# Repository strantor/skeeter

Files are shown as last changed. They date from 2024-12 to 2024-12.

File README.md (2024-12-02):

# skeeter
- Plastic welding spoolgun
- Over Engineered hot glue gun
- Under Engineered 3D printer (handheld)
- 3D pen on steroids

This tool is designed to make the welding together of 3D printed parts go quickly.
It operates from DeWalt 20V battery power or a 24V power supply; there are two handle variants you can print depending on how you want to power it.



BOM:
1. 1X pair of printed parts
2. 1x [DeWalt Battery holder](https://www.amazon.com/gp/product/B0C282C27R/ref=ppx_yo_dt_b_search_asin_title?ie=UTF8&psc=1) (if you want battery powered)
3. 1x Orbiter 2 extruder
4. 1x 2510 fan 24V
5. 1x [Pololu DC motor](https://www.pololu.com/product/3491)
6. 1x [Peopoly Lancer Long hotend](https://peopoly.net/products/magneto-x-lancer-melt-zone?variant=49972216135962)
7. 1x [FA2-16/WEK drill trigger motor controller](https://www.amazon.com/gp/product/B08PKZ464X/ref=ppx_yo_dt_b_search_asin_title?ie=UTF8&psc=1)
8. 1x [MKS THR42 3d printer toolhead board](https://makerbase3d.com/product/mks-thr36-thr42-board/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)
9. 4x 8-32 x0.5" countersunk screws
10. 4X M3x5mm standoffs
11. assortment of misc M3 screws
12. 18 awg wire 

Instructions:
1. print the parts. handle1.stl is for non-battery power and handle2 is for DeWalt battery power; you don't need both, just one or the other.
2. remove the stepper motor from the orbiter extruder
3. fabricate/machine a motor adapter plate and shaft adapter to mount the Pololu motor in place of the orbiter stepper
4. tap holes in the 3D printed parts. The 4 holes that hold the top part to the bottom are 8-32 and everything else is M3
5. assemble everything. T
6. Connect to the gun to PC via USB and flash the skeeter.uf2 file to the THR42 board via [MKS's firmware update instructions](https://github.com/makerbase-mks/MKS-THR36-THR42-UTC?tab=readme-ov-file#thr3642-firmware-update) . Ignore all the stuff about klipper config; this is not klipper firmware, it is a totally separate firmware that I wrote, to control the THR42 board as it's own standalone thing.
7. With the gun connected, to PC, connect to it using a terminal app like Putty or Arduino serial monitor. Send it a temperature (C) setpoint command like "S220" (without quotes) to set 220C.
8. It shouldn't need any PID tune adjustments if using Peopoly Lancer Long, but if using something else you can change the PID parameters by typing (for example): [Pxxx.xxx - Set PID Proportional constant. Ex: P2.25], [Ixxx.xxx - Set PID Integral constant. Ex: I0.25], [Dxxx.xxx - Set PID Derivative constant. Ex: D1.525]
9. Go shoot plastic!

The skeeter.uf2 firmware file is generated by Arduino IDE using the skeeter.ino file which you are welcome to modify however you want.

**NOTE: there is no low voltage cutout circuit on this tool so if you use the battery powered version, it is 100% capable of discharging your battery down to damaging levels!**

Help wanted! it's kinda silly to have to remove the stepper from the orbiter extruder and replace it with a DC motor (and go to the hassle of fabricating the adapters), when there is a THR42 board already on the tool that has a TMC2209 stepper driver on it. If someone wants to help out, figure out how to take the high voltage PWM signal from the trigger control and drop it down to a low voltage input (voltage divider? optocoupler?) to the THR42 board. Then use the THR42 board to control the stepper in a quasi-analog fashion (as you would expect a trigger-controlled tool to operate).

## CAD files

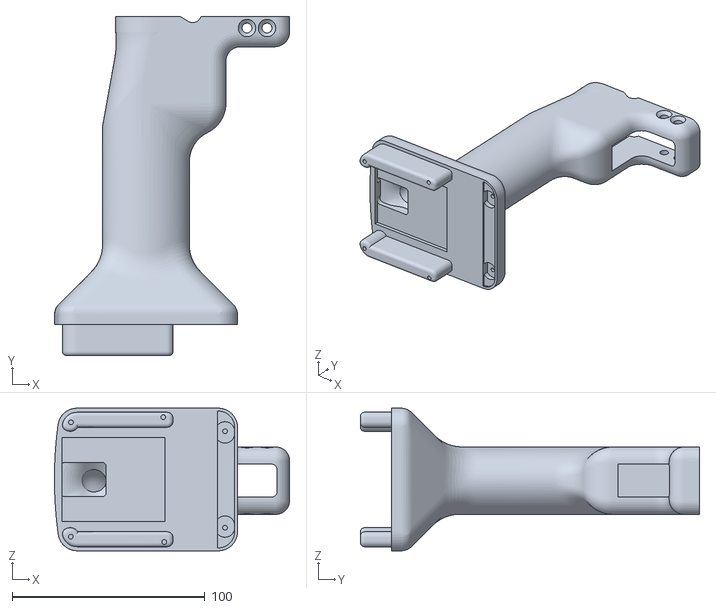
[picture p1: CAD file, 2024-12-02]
handle2.stl
122.0 x 175.8 x 74.0

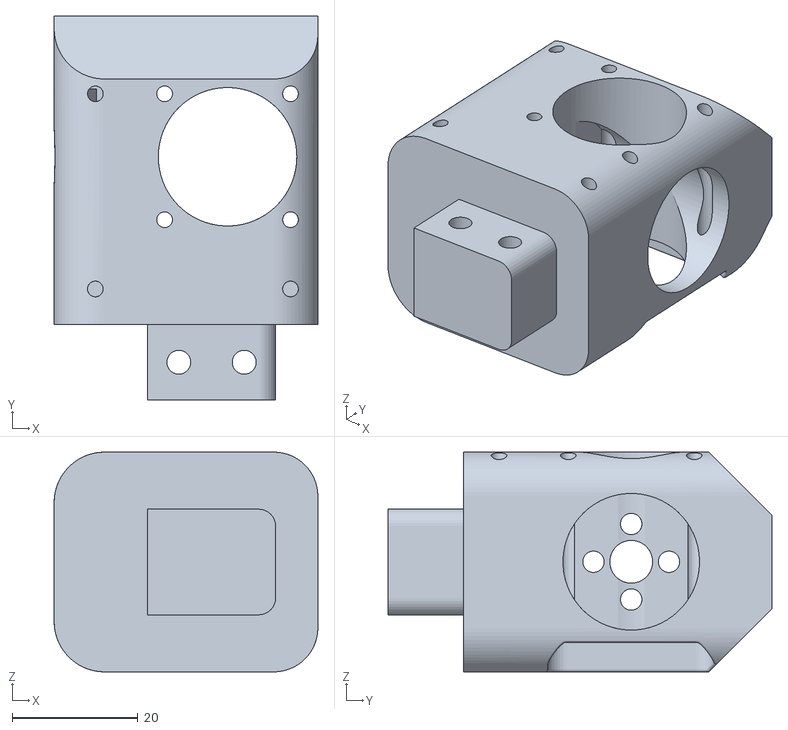
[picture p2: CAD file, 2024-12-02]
upper.stl
41.9 x 61.0 x 34.9

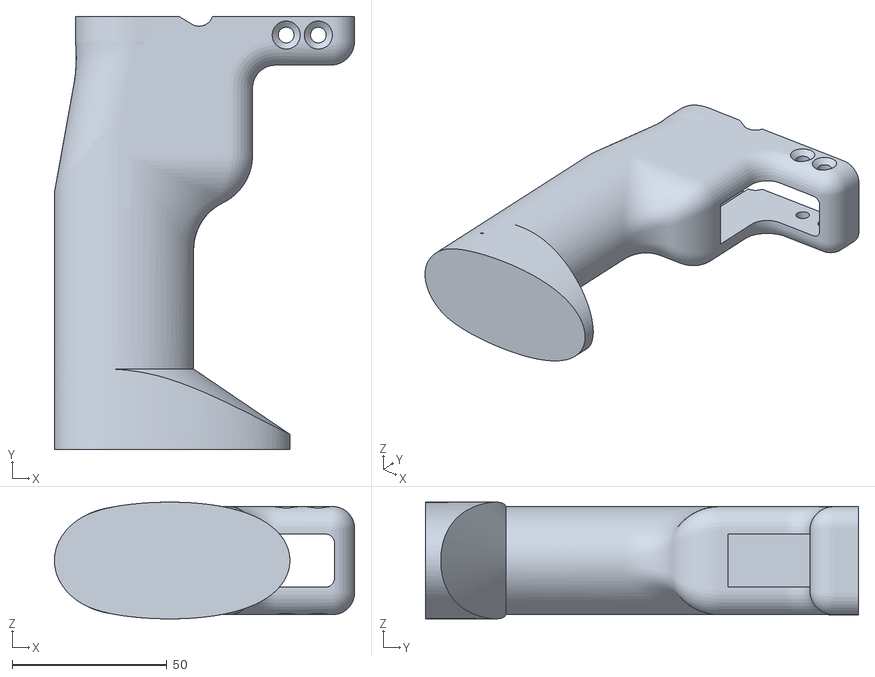
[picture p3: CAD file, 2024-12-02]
handle1.stl
97.0 x 139.9 x 37.7

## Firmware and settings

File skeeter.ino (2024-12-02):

// 12/2/24 Chuck Staton

// this is written for RP2040 (MKS THR42 board) in Arduino IDE. You must use https://github.com/earlephilhower/arduino-pico/
// setup instructions for installing the github package: https://www.tomshardware.com/how-to/program-raspberry-pi-pico-with-arduino-ide

// I'm shit at programming anything but Python. This is a collection of other people's code that I found online, copied, pasted, and modified to fit my needs. 
// I don't remember where some of it came from, but here is a list of citations that should cover most of the important stuff:
// - Arduino PID temperature implementation (was kinda wack, needed help, but "worked"): https://electronoobs.com/eng_arduino_tut24_code2.php#google_vignette
// - Serial input basics. I think it's an excellent tutorial and serial in Arduino just sucks. I could be wrong; the tutorial could suck. https://forum.arduino.cc/t/serial-input-basics-updated/382007
// - Abducar's thermistor lookup table code. https://forum.arduino.cc/t/how-to-use-ntc-100k-thermistor-to-measure-high-temperature/472821/13
// - How to EEPROM https://docs.arduino.cc/learn/programming/eeprom-guide/

// The EEPROM stuff is Earle F. Philhower's simulation of EEPROM which is actually stored on Pico's flash, so try not to write too often to it.
// Commands which can be typed into the serial monitor:
// Sxxx - Set temperature (C). Ex: "S235" - sets setpoint to 235C
// Pxxx.xxx - Set PID Proportional constant. Ex: P2.25
// Ixxx.xxx - Set PID Integral constant. Ex: I0.25
// Dxxx.xxx - Set PID Derivative constant. Ex: D1.525
// PID and temperature setpoints survive power cycle, so just set it initially and it should work whenever powered on.

// TODO: 
// - Make a way to attach a potentiometer or something so you don't have to connect to PC to change the temp setpoint
// - Utilize the THR42's onboard TMC2209 to control a stepper in quasi-analog style in response to PWM input from finger trigger controller (emulate a DC motor). 

#include <EEPROM.h>
#define THERMISTOR_PIN A0
#define NUMTEMPS 20
// The following lookup table was found online and is not an exact match for the Peopoly thermistor but close enough. 
// I did try the converted lookup table from the peopoly 
short temptable[NUMTEMPS][2] = {
   {1, 821},
   {54, 252},
   {107, 207},
   {160, 182},
   {213, 165},
   {266, 152},
   {319, 141},
   {372, 131},
   {425, 123},
   {478, 115},
   {531, 107},
   {584, 100},
   {637, 93},
   {690, 86},
   {743, 78},
   {796, 70},
   {849, 60},
   {902, 49},
   {955, 34},
   {1008, 3}
};
int PWM_pin = 0;
float temperature_read = 0.0;
float set_temperature;
float PID_error = 0;
float previous_error = 0;
float elapsedTime, Time, timePrev;
int PID_value = 0;
//int kp = 9.1;   int ki = 0.3;   int kd = 1.8;
//float kp = 9.1;   float ki = 0.3;   float kd = 1.8;
float kp;
float ki;
float kd;
float PID_p = 0;    
float PID_i = 0;    
float PID_d = 0;
float PID_value_unlimited;
const byte numChars = 32;
char receivedChars[numChars];   // an array to store the received data
char firstLetter = '0';
boolean newData = false;
bool startup = true;
byte addr10;

void setup()
{
   pinMode(PWM_pin,OUTPUT); //HE0 output
   Time = millis();
   Serial.begin(9600);
   Serial.println("Starting temperature exerciser.");
   pinMode(1, OUTPUT); //fan0 output
   EEPROM.begin(512);
}

void loop()
{
  if (startup == true){
    addr10 = EEPROM.read(10);
    if (addr10 != 2){ // first run ever
      set_temperature = 215;
      saveTempSetting();
      kp = 1.0;
      ki = 0.2;
      kd = 1.0;
      savePIDSettings();
      EEPROM.write(10, 2);
      if (EEPROM.commit()) {
        Serial.println("EEPROM successfully committed");
      }else {
        Serial.println("ERROR! EEPROM commit failed");
      }
    }else{
      byte temp1 = EEPROM.read(0); // address 0 = temperature setpoint
      byte temp2 = EEPROM.read(1);
      //if (temp2 == 255)
      if (temp2 == 1){
        set_temperature = temp1+255;
      }else{
        set_temperature = temp1;
      }
      EEPROM.get(20,kp);    
      EEPROM.get(30,ki); 
      EEPROM.get(40,kd); 
    }
    startup = false;
  }
   int rawvalue = analogRead(THERMISTOR_PIN);
   int celsius = read_temp();
   int fahrenheit = (((celsius * 9) / 5) + 32);
   if (celsius < 17){
    digitalWrite(1, LOW); 
   }
   if (celsius >= 18){
    digitalWrite(1, HIGH); 
   }
   // First we read the real value of temperature
  temperature_read = celsius;
  //Next we calculate the error between the setpoint and the real value
  PID_error = set_temperature - temperature_read;
  //Calculate the P value
  PID_p = kp * PID_error;
  //Calculate the I value in a range on +-3
  if(-3 < PID_error <3)
  {
    PID_i = PID_i + (ki * PID_error);
  }
  else{
    PID_i = 0; //added to prevent integral windup
  }
  if (PID_i > 127){
    PID_i = 127; //added integral limit
  }
  if (PID_i < -127){
    PID_i = -127; //added integral limit
  }

  //For derivative we need real time to calculate speed change rate
  timePrev = Time;                            // the previous time is stored before the actual time read
  Time = millis();                            // actual time read
  elapsedTime = (Time - timePrev) / 1000; 
  //Now we can calculate the D calue
  PID_d = kd*((PID_error - previous_error)/elapsedTime);
  //Final total PID value is the sum of P + I + D
  PID_value = PID_p + PID_i + PID_d;
  PID_value_unlimited = PID_value;
  //We define PWM range between 0 and 255
  if(PID_value < 0)
  {    PID_value = 0;    }
  if(PID_value > 255)  
  {    PID_value = 255;  }
  if (celsius > set_temperature){
    PID_value = 0;
  }
  //Now we can write the PWM signal to the mosfet on digital pin D3
  analogWrite(PWM_pin,PID_value);
  previous_error = PID_error;     //Remember to store the previous error for next loop.
  //int kp = 9.1;   int ki = 0.3;   int kd = 1.8;
//  Serial.print("Addr10: ");
//  Serial.print(addr10);
//  Serial.print(", Addr20: ");
//  Serial.print(EEPROM.read(20));
//  Serial.print(", Addr21: ");
//  Serial.print(EEPROM.read(21));
//  Serial.print(", Addr22: ");
//  Serial.print(EEPROM.read(22));
//  Serial.print(", Addr23: ");
//  Serial.print(EEPROM.read(23));
  Serial.print("PID_p: ");
  Serial.print(PID_p);
  Serial.print(", PID_i: ");
  Serial.print(PID_i);
  Serial.print(", PID_d: ");
  Serial.print(PID_d);
  Serial.print(", P: ");
  Serial.print(kp);
  Serial.print(", I: ");
  Serial.print(ki);
  Serial.print(", D: ");
  Serial.print(kd);
  Serial.print(", setP: ");
  Serial.print(set_temperature);
  Serial.print(", temp: ");
  Serial.print(celsius);
  Serial.print("C, error: ");
  Serial.print(PID_error);
  Serial.print(", output: ");
  Serial.print(PID_value);
  Serial.print(", outputUnlim: ");
  Serial.println(PID_value_unlimited);
  
  recvWithEndMarker();
  showNewData();
  
  delay(300);

}

int read_temp()
{
   int rawtemp = analogRead(THERMISTOR_PIN);
   int current_celsius = 0;

   byte i;
   for (i=1; i<NUMTEMPS; i++)
   {
      if (temptable[i][0] > rawtemp)
      {
         int realtemp  = temptable[i-1][1] + (rawtemp - temptable[i-1][0]) * (temptable[i][1] - temptable[i-1][1]) / (temptable[i][0] - temptable[i-1][0]);

         if (realtemp > 500)
            realtemp = 500; 

         current_celsius = realtemp;

         break;
      }
   }

   // Overflow: We just clamp to 0 degrees celsius
   if (i == NUMTEMPS)
   current_celsius = 0;

   return current_celsius;
}
void recvWithEndMarker() {
    static byte ndx = 0;
    char endMarker = '\n';
    char rc;
    
    while (Serial.available() > 0 && newData == false) {
        rc = Serial.read();

        if (rc != endMarker) {
            receivedChars[ndx] = rc;
            ndx++;
            if (ndx >= numChars) {
                ndx = numChars - 1;
            }
        }
        else {
            receivedChars[ndx] = '\0'; // terminate the string
            ndx = 0;
            newData = true;
        }
    }
}

void showNewData() {
  if (newData == true) {
    char Sflag = 'S';
    char Pflag = 'P';
    char Iflag = 'I';
    char Dflag = 'D';
    char firstLetter = receivedChars[0];
    char DataChars[10];
    for (int i=0; i<11; i++) {
      DataChars[i] = receivedChars[i+1];
    }
    if (Sflag == firstLetter){     
      Serial.print("Temperature Setpoint change sent: ");
      Serial.println(DataChars);
      set_temperature = atof(DataChars);
      saveTempSetting();
    }
    if (Pflag == firstLetter){     
      Serial.print("Proportional factor change sent: ");
      Serial.println(DataChars);
      kp = atof(DataChars);
      savePIDSettings();
    }
    if (Iflag == firstLetter){     
      Serial.print("Integral factor change sent: ");
      Serial.println(DataChars);
      ki = atof(DataChars);
      savePIDSettings();
    }
    if (Dflag == firstLetter){     
      Serial.print("Derivative factor change sent: ");
      Serial.println(DataChars);
      kd = atof(DataChars);
      savePIDSettings();
    }
//    Serial.print("This just in ... ");
//    Serial.println(receivedChars);
    newData = false;
  }
}

void savePIDSettings() {
    //  uint8_t bytes[4] = { 0, 1, 2, 3 }; // fill this array with the four bytes you received
    //static_assert(sizeof(float) == 4, "float size is expected to be 4 bytes");
    //float f;
    //memcpy (&f, bytes, 4);
//  byte *ptr;   
//  ptr = (byte*)&kp;  //ptr holds beginning address of 4-byte memory space containing value of x 
//  for (int i = 0, address = 20; i < 4; i++, address++, ptr++)
//  {
//    EEPROM.write(address, *ptr);
//  }
  EEPROM.put(20,kp);
  EEPROM.put(30,ki);
  EEPROM.put(40,kd);
  if (EEPROM.commit()) {
    Serial.println("EEPROM successfully committed");
  }else {
    Serial.println("ERROR! EEPROM commit failed");
  }
}

void saveTempSetting() {
    if (set_temperature >310){
    set_temperature=310;
  }
  // EEprom can only hold up to 255
  if (set_temperature >254){
    EEPROM.write(0, set_temperature-255);
    EEPROM.write(1, 1);
  }else{
    EEPROM.write(0, set_temperature);
    EEPROM.write(1, 0);
  }
  
  if (EEPROM.commit()) {
    Serial.println("EEPROM successfully committed");
  }else {
    Serial.println("ERROR! EEPROM commit failed");
  }
}

//
//int sensorPin = A0;    // 100k thermistor
//int sensorValue = 0;  // variable to store the value coming from the sensor
//
//// the setup function runs once when you press reset or power the board
//void setup() {
//  // initialize serial communication:
//  Serial.begin(9600);
//  // initialize digital pin LED_BUILTIN as an output.
//  pinMode(1, OUTPUT);
//}
//
//// the loop function runs over and over again forever
//void loop() {
//  sensorValue = analogRead(sensorPin);
//  Serial.println(sensorValue);
//  // convert the value to resistance
//  float reading;
//  reading = (1023 / sensorValue)  - 1;     // (1023/ADC - 1) 
//  reading = 100000 * reading;  // 100K / (1023/ADC - 1)
//  Serial.print("Thermistor resistance "); 
//  Serial.println(reading);
//  digitalWrite(1, HIGH);   // turn the LED on (HIGH is the voltage level)
//  delay(1000);                       // wait for a second
//  digitalWrite(1, LOW);    // turn the LED off by making the voltage LOW
//  delay(1000);                       // wait for a second
//}
